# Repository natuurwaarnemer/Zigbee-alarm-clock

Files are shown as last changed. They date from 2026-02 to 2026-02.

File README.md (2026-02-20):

# Zigbee Wekker voor Home Assistant

Een slimme wekker gemaakt met ESP32-C6 die integreert met Home Assistant via WiFi (met Zigbee upgrade pad).

## Features

- 🕐 7 instelbare alarmen (één per dag van de week)
- 📱 Besturing via Home Assistant dashboard
- 🔊 Piëzo buzzer voor alarm met geleidelijk toenemend volume
- 🔘 Fysieke knop om alarm uit te zetten
- 💡 Triggert automatisch acties in Home Assistant (bijv. licht aan)
- 📟 OLED display (1.3", 128x64) toont tijd, datum en volgend alarm
- 📶 WiFi verbinding via ESPHome (Zigbee upgrade mogelijk)
- 🌙 Weergavehelderheid aanpasbaar (dim 's nachts)
- 🗓️ Weekend/werkdag modus

## Benodigdheden

| Component | Type | Opmerkingen |
|---|---|---|
| Microcontroller | ESP32-C6 (Seeed Studio) | Met ingebouwde WiFi + Zigbee |
| Display | OLED 1.3" 128x64 I2C | SSD1306 driver, blauw |
| Buzzer | Piezo buzzer (Grove/Actief) | 3-5V |
| Knop | Drukknop 19mm (DE-GQ19H-10) | Normaal open |
| Voeding | USB-C 5V adapter | Minimaal 1A |

Zie [hardware/components.md](hardware/components.md) voor de volledige lijst met bestelnummers.

## Snelstart

1. Sluit hardware aan volgens [hardware/wiring-diagram.md](hardware/wiring-diagram.md)
2. Volg [docs/SETUP.md](docs/SETUP.md) voor installatie en configuratie
3. Voeg Home Assistant helpers toe via [home-assistant/configuration.yaml](home-assistant/configuration.yaml)
4. Importeer het dashboard via [home-assistant/dashboard.yaml](home-assistant/dashboard.yaml)
5. (Optioneel) Print de behuizing via [3d-models/](3d-models/)

## Repository Structuur

```
Zigbee-alarm-clock/
├── esphome/
│   ├── zigbee-alarm-clock.yaml     # Primaire ESPHome configuratie (WiFi)
│   └── secrets.yaml.example        # Sjabloon voor WiFi/API gegevens
├── platformio/                     # Alternatief: native Zigbee (gevorderd)
│   ├── platformio.ini
│   ├── src/
│   │   ├── main.cpp
│   │   ├── display.cpp/h
│   │   ├── zigbee.cpp/h
│   │   └── alarm.cpp/h
│   └── README.md
├── home-assistant/
│   ├── configuration.yaml          # Helpers definitie
│   ├── automations.yaml            # Voorbeeldautomatiseringen
│   ├── dashboard.yaml              # Dashboard kaart
│   └── README.md
├── hardware/
│   ├── wiring-diagram.md           # Gedetailleerde aansluitgids
│   ├── components.md               # Onderdelen lijst (BOM)
│   └── photos/
├── 3d-models/
│   ├── case-v1.scad                # OpenSCAD bronbestand
│   └── README.md
├── docs/
│   ├── SETUP.md                    # Stap-voor-stap installatie
│   ├── TROUBLESHOOTING.md          # Veelvoorkomende problemen
│   └── ARCHITECTURE.md             # Systeemontwerp (Engels)
├── .gitignore
└── LICENSE
```

## Schermafdrukken / Foto's

> 📸 Foto's worden toegevoegd zodra de hardware is geassembleerd.
> Zie [hardware/photos/](hardware/photos/) voor placeholders.

## Technische Details

### Pinnen Configuratie

| Functie | GPIO |
|---|---|
| OLED SDA | GPIO6 |
| OLED SCL | GPIO7 |
| Buzzer (+) | GPIO8 |
| Knop | GPIO9 |

### Stroomverbruik

| Toestand | Stroom |
|---|---|
| Standby | ~80 mA |
| Display actief | ~100 mA |
| Alarm actief | ~120 mA |
| WiFi piek | ~150 mA |

## Zigbee Upgrade

Dit project gebruikt momenteel WiFi via ESPHome. De ESP32-C6 heeft ingebouwde
Zigbee hardware. Zodra ESPHome native Zigbee ondersteunt, is een upgrade mogelijk
zonder hardware wijzigingen. De `platformio/` map bevat een Zigbee implementatie
als referentie voor gevorderde gebruikers.

Zie [docs/ARCHITECTURE.md](docs/ARCHITECTURE.md) voor het migratiepad.

## Bekende Beperkingen

- ESPHome heeft nog geen native Zigbee ondersteuning voor ESP32-C6
- De buzzer vereist een actieve buzzer of passieve piëzo (zie BOM)
- OTA updates vereisen WiFi verbinding
- NTP tijd synchronisatie vereist internetverbinding

## Bijdragen

Pull requests zijn welkom! Zie [docs/ARCHITECTURE.md](docs/ARCHITECTURE.md) voor
de systeemarchitectuur en bijdragenrichtlijnen.

## Changelog

### v1.0.0 (2026)
- Initiële release
- ESPHome WiFi implementatie
- 7 instelbare alarmen
- OLED display
- Home Assistant integratie
- PlatformIO Zigbee referentie implementatie
- 3D printbare behuizing

## Licentie

MIT License - zie [LICENSE](LICENSE) voor details.

Copyright (c) 2026 Ruud Hogenberg

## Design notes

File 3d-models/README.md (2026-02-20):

# 3D-geprinte Behuizing - Zigbee Wekker

## Overzicht

De behuizing is ontworpen in OpenSCAD (parametrisch, aanpasbaar) en is 
printbaar zonder supports.

## Benodigdheden

| Item | Specificatie |
|---|---|
| 3D Printer | FDM printer, minimaal 100x80 mm printoppervlak |
| Filament | PLA 1.75 mm, ~50 gram |
| Kleur | Naar keuze (zwart aanbevolen) |

## Printinstellingen

| Instelling | Waarde |
|---|---|
| Laagdikte | 0.2 mm |
| Vulling | 20% (gyroid of grid) |
| Omtreklijnen | 3 |
| Printtemperatuur PLA | 200-210°C |
| Bed temperatuur | 60°C |
| Supports | NIET nodig |
| Brim | Aanbevolen (3-5 mm) voor het deksel |

## Onderdelen

Het model bestaat uit 2 onderdelen die apart worden afgedrukt:

### 1. Body (Onderstuk) - `case_body()`
- Buitenafmetingen: 100 x 75 x 40 mm
- Bevat: montage palen voor ESP32-C6 en OLED, USB-C poort uitsparing,
  snap-fit clips, kabelgeleiding
- Printoriëntatie: **Platte onderkant naar beneden** (geen supports nodig)

### 2. Deksel (Bovenstuk) - `case_lid()`
- Buitenafmetingen: 100 x 75 x 6 mm  
- Bevat: display venster uitsparing (35x28 mm), knop gat (19.5 mm Ø),
  snap-fit groeven
- Printoriëntatie: **Platte binnenkant naar beneden** (geen supports nodig)

## STL Exporteren vanuit OpenSCAD

### Body exporteren:
1. Open `case-v1.scad` in OpenSCAD
2. Zoek de render regels onderaan het bestand
3. Verwijder `//` voor `case_body();` en voeg `//` toe voor andere render regels
4. Klik F6 (Render)
5. Klik File → Export → Export as STL

### Deksel exporteren:
1. Zelfde procedure, maar activeer `case_lid();`

## Parameters Aanpassen

Open `case-v1.scad` en pas de parameters bovenaan het bestand aan:

```openscad
// Buitenafmetingen - vergroot voor meer ruimte binnenin
case_width  = 100;   // breedte in mm
case_depth  = 75;    // diepte in mm
case_height = 40;    // hoogte in mm
wall_thickness = 2.5; // wanddikte in mm
```

**Let op toleranties:** Bij grote printers of andere filamenttypes kan het nodig
zijn `fit_tol` aan te passen (standaard 0.2 mm).

## Assemblage

### Benodigdheden voor assemblage
- 4x M2x4mm schroeven (voor ESP32-C6)
- 4x M2x4mm schroeven (voor OLED module, optioneel)
- Dubbelzijdig tape of hot glue (alternatief voor schroeven)
- Kleine platte schroevendraaier

### Stappen
1. Druk beide onderdelen af
2. Verwijder brim/rand voorzichtig
3. Test of de snap-fit past (body + deksel klikken samen)
4. Monteer ESP32-C6 module op de 4 montage palen (M2 schroeven)
5. Monteer OLED display (gericht naar het display venster in het deksel)
6. Verleg kabels netjes via de kabelgeleiding
7. Klik het deksel op de body
8. Test alle functies voor definitieve montage

## Maatvoering

```
Bovenaanzicht deksel:
┌────────────────────────────────────────────┐
│                                            │
│    ┌──────────────────────┐    ○           │
│    │   Display venster    │  (knop)        │
│    │    35 x 28 mm        │   19.5mm Ø     │
│    └──────────────────────┘                │
│                                            │
└────────────────────────────────────────────┘
          100 mm breed x 75 mm diep

Zijaanzicht:
┌────────────────────────────────────────────┐  ← Deksel (6mm)
│                                            │
│                                            │
│                                            │  ← Body (40mm)
│  [USB-C]                                   │
└────────────────────────────────────────────┘
```

## Problemen Oplossen

**Deksel past niet:**
- Vergroot `fit_tol` van 0.2 naar 0.3 of 0.4 mm en herprint
- Schuur de binnenkant van de snap-fit groeven lichtjes bij

**Display venster te klein:**
- Meet je OLED module nauwkeurig na
- Pas `display_w` en `display_h` aan in het SCAD bestand

**Knop gat te nauw:**
- Pas `button_dia` aan (verhoog met 0.2-0.5 mm)

**Montagepalen te smal/breed:**
- Pas `post_hole_dia` aan voor M2 schroeven (standaard 2.1 mm)

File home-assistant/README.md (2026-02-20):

# Home Assistant Configuratie - Zigbee Wekker

## Overzicht

Deze map bevat de Home Assistant configuratie voor de Zigbee Wekker:

- `configuration.yaml` - Helpers (input_datetime, input_boolean)
- `automations.yaml` - Automatiseringen voor alarm sync en acties
- `dashboard.yaml` - Lovelace dashboard kaart

## Installatie

### Stap 1: Helpers toevoegen

Voeg de inhoud van `configuration.yaml` toe aan je Home Assistant
`configuration.yaml` (of aan een apart bestand via `!include`).

Herstart Home Assistant na het toevoegen van de helpers.

**Via de UI (aanbevolen):**
1. Ga naar Instellingen → Apparaten & Services → Helpers
2. Klik "+ Maak Helper"
3. Maak alle `input_datetime` en `input_boolean` helpers aan zoals beschreven

### Stap 2: Apparaat toevoegen (ESPHome)

1. Zorg dat de wekker is geflasht en verbonden met WiFi
2. Home Assistant detecteert het apparaat automatisch via ESPHome integratie
3. Ga naar Instellingen → Apparaten & Services → ESPHome
4. Accepteer het nieuwe apparaat "Zigbee Wekker"

### Stap 3: Automatiseringen toevoegen

**Via de UI:**
1. Ga naar Instellingen → Automatiseringen
2. Importeer `automations.yaml` of maak handmatig aan

**Via YAML:**
Voeg inhoud van `automations.yaml` toe aan je `automations.yaml`

### Stap 4: Dashboard toevoegen

1. Ga naar je gewenste dashboard
2. Klik het bewerkingspictogram (potlood)
3. Klik "Kaart toevoegen" → "Handmatig"
4. Plak de inhoud van `dashboard.yaml`

## Entiteiten

Na installatie zijn deze entiteiten beschikbaar:

### Van de wekker (ESPHome)
| Entiteit | Type | Beschrijving |
|---|---|---|
| `binary_sensor.zigbee_wekker_wifi_verbonden` | Sensor | WiFi status |
| `sensor.zigbee_wekker_volgend_alarm` | Sensor | Volgende alarm tijd |
| `sensor.zigbee_wekker_wifi_signaalsterkte` | Sensor | WiFi signaal (dBm) |
| `switch.zigbee_wekker_alarm_hoofdschakelaar` | Schakelaar | Master aan/uit |
| `switch.zigbee_wekker_alarm_maandag_aan` | Schakelaar | Maandag alarm |
| ... | ... | Herhaal voor alle 7 dagen |
| `number.zigbee_wekker_alarm_maandag_uur` | Nummer | Alarm uur |
| `number.zigbee_wekker_alarm_maandag_minuut` | Nummer | Alarm minuut |
| ... | ... | Herhaal voor alle 7 dagen |

### HA Helpers (aangemaakt via configuration.yaml)
| Entiteit | Type | Beschrijving |
|---|---|---|
| `input_datetime.alarm_maandag` | Tijd invoer | Alternatief tijdsinvoer |
| `input_boolean.alarm_maandag_aan` | Schakelaar | Alternatief schakelaar |
| `input_boolean.alarm_hoofdschakelaar` | Schakelaar | Hoofd schakelaar HA kant |

## Troubleshooting

**Apparaat verschijnt niet:**
- Controleer WiFi verbinding
- Herstart de ESPHome integratie
- Check de logs: Instellingen → Systeem → Logboek

**Alarm synchroniseert niet:**
- Check dat de automatisering actief is
- Verifieer entiteitsnamen in de automatisering
- Bekijk trace in automatiseringseditor

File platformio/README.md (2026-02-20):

# PlatformIO - Native Zigbee Implementatie (Gevorderd)

Dit is de **alternatieve** implementatie van de Zigbee Wekker met native Zigbee
via de ESP-Zigbee-SDK. De primaire implementatie (via ESPHome + WiFi) staat in
de `esphome/` map.

## Wanneer deze versie gebruiken?

Gebruik de PlatformIO versie als je:
- Native Zigbee communicatie wilt (geen WiFi vereist)
- Meer controle wilt over de Zigbee device definitie
- Gevorderd bent met embedded programmeren
- Een Zigbee coordinator hebt (bijv. SMLIGHT SLZB-MR3 of Sonoff Zigbee Dongle)

## Vereisten

### Software
- [PlatformIO IDE](https://platformio.org/) (VS Code extensie aanbevolen)
- ESP-IDF v5.x (automatisch geïnstalleerd door PlatformIO)
- ESP-Zigbee-SDK (via ESP-IDF component manager)

### Hardware
- ESP32-C6 development board (Seeed Studio XIAO ESP32C6 of vergelijkbaar)
- Zigbee coordinator op hetzelfde netwerk als Home Assistant

## Installatie

### Stap 1: PlatformIO installeren

1. Installeer [VS Code](https://code.visualstudio.com/)
2. Installeer de PlatformIO extensie
3. Open de `platformio/` map als project

### Stap 2: ESP-Zigbee-SDK component toevoegen

Maak een `idf_component.yml` aan in de `platformio/` map:

```yaml
dependencies:
  espressif/esp-zigbee-sdk: ">=1.1.0"
```

Of voeg toe via ESP-IDF component manager:
```bash
cd platformio
idf.py add-dependency "espressif/esp-zigbee-sdk"
```

### Stap 3: sdkconfig aanpassen

Maak een `sdkconfig.defaults` bestand aan in de `platformio/` map:

```
CONFIG_ZB_ENABLED=y
CONFIG_ZB_ZED=y
CONFIG_ZB_RADIO_NATIVE=y
CONFIG_ZB_GP_ENABLED=n
CONFIG_FREERTOS_HZ=1000
```

### Stap 4: Compileren en uploaden

```bash
cd platformio
pio run --target upload
pio device monitor --baud 115200
```

## Zigbee Configuratie in Home Assistant

### MQTT/Zigbee2MQTT

Als je Zigbee2MQTT gebruikt, wordt het apparaat automatisch gedetecteerd als
een "Alarm Clock" device na pairen.

**Pairen:**
1. Zet het apparaat in pairmodus (eerste keer automatisch, daarna via serieel commando)
2. Open Zigbee2MQTT dashboard
3. Klik "Permit join"
4. Het apparaat verschijnt als "Zigbee Alarm Clock"

### ZHA (Zigbee Home Automation)

1. Ga naar Instellingen → Apparaten & Services → ZHA
2. Klik "Apparaat toevoegen"
3. Druk de resetknop op het ESP32-C6 board

## Codestructuur

```
platformio/src/
├── main.cpp      # Arduino setup/loop, button handling, time management
├── display.cpp   # SSD1306 OLED rendering
├── display.h     # Display API
├── alarm.cpp     # Alarm logic, NVS storage, buzzer PWM
├── alarm.h       # Alarm API
├── zigbee.cpp    # Zigbee stack, clusters, attribute handling
└── zigbee.h      # Zigbee API
```

## Bekende Beperkingen

- ESP-Zigbee-SDK is nog in actieve ontwikkeling - API kan veranderen
- Arduino framework heeft beperkte compatibiliteit met ESP-Zigbee-SDK
  (gebruik `espidf` framework voor productie)
- Geen OTA via Zigbee (gebruik seriële verbinding voor updates)
- Zigbee2MQTT heeft mogelijk custom converter nodig voor het custom cluster

## Referenties

- [ESP-Zigbee-SDK GitHub](https://github.com/espressif/esp-zigbee-sdk)
- [ESP-IDF Zigbee Examples](https://github.com/espressif/esp-idf/tree/master/examples/zigbee)
- [Zigbee2MQTT Custom Devices](https://www.zigbee2mqtt.io/advanced/support-new-devices/01_support_new_devices.html)

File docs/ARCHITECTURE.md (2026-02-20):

# System Architecture - Zigbee Alarm Clock

## Overview

The Zigbee Alarm Clock is a WiFi/Zigbee-enabled smart alarm clock built on the
ESP32-C6 microcontroller. It integrates with Home Assistant for alarm management
and automation.

```
┌─────────────────────────────────────────────────────────────────┐
│                      Home Assistant                             │
│  ┌─────────────────────────────────────────────────────────┐   │
│  │  ESPHome Integration   │  Input Helpers  │  Dashboard   │   │
│  └─────────────────────────────────────────────────────────┘   │
└──────────────────────────────┬──────────────────────────────────┘
                               │ WiFi (ESPHome native API)
                               │ or Zigbee (future / platformio/)
┌──────────────────────────────▼──────────────────────────────────┐
│                       ESP32-C6                                  │
│                                                                 │
│  ┌──────────────┐  ┌──────────────┐  ┌──────────────────────┐  │
│  │  ESPHome     │  │  Alarm Logic │  │   Display Driver     │  │
│  │  Framework   │  │  (Globals +  │  │   (SSD1306 I2C)      │  │
│  │  (WiFi/API)  │  │   Scripts)   │  │   GPIO6/7            │  │
│  └──────────────┘  └──────────────┘  └──────────────────────┘  │
│         │                │                                      │
│  ┌──────▼──────┐  ┌──────▼──────┐  ┌──────────────────────┐   │
│  │  NTP / HA   │  │  PWM Buzzer │  │   Button Handler     │   │
│  │  Time Sync  │  │  (LEDC)     │  │   GPIO9 (pull-up)    │   │
│  └─────────────┘  │  GPIO8      │  └──────────────────────┘   │
│                   └─────────────┘                               │
└─────────────────────────────────────────────────────────────────┘
        │                    │                    │
   ┌────▼────┐          ┌────▼────┐          ┌────▼────┐
   │  OLED   │          │  Buzzer │          │  Button │
   │ 128x64  │          │ GPIO8   │          │ GPIO9   │
   └─────────┘          └─────────┘          └─────────┘
```

## Components

### 1. ESPHome Firmware (`esphome/`)

**Primary implementation** - recommended for most users.

| Component | Implementation |
|---|---|
| Time sync | `homeassistant` platform + SNTP fallback |
| Display | `ssd1306_i2c` platform, lambda rendering |
| Alarm logic | `script` components + `globals` |
| Button | `gpio` binary_sensor with debounce |
| Buzzer | `ledc` PWM output + manual control in scripts |
| WiFi | Native ESP32 WiFi + captive portal fallback |
| HA API | Native ESPHome API (encrypted) |

**Alarm checking:** A `script` runs every minute triggered by `on_time`.
It checks each day's alarm against current time and day-of-week. If a match
is found, the `alarm_start` script is invoked.

**Display rendering:** The display lambda runs every second. It reads globals
(`alarm_active`, `next_alarm_str`) and the HA time component to render the UI.
During an active alarm, the display blinks to attract attention.

**Fade-in buzzer:** The `alarm_beep_loop` script uses a global `buzzer_step`
(0-10) to gradually increase the PWM duty cycle over the first 10 beep cycles,
creating a gentle wake-up experience.

### 2. Home Assistant

**Alarm configuration storage:**
- `number` entities (hour/minute per day) - stored on the ESP32 in flash
- `switch` entities (enabled per day) - stored on the ESP32 in flash
- `input_datetime` / `input_boolean` helpers - optional HA-side storage

**Automations:**
- Sync helpers → device number/switch entities
- Trigger lights/scenes on button press event
- Send mobile notification on alarm trigger
- Vacation mode (disable all alarms)

**Dashboard:** Lovelace vertical-stack card with entities, buttons for test/stop.

### 3. PlatformIO / Native Zigbee (`platformio/`)

**Alternative implementation** for advanced users wanting native Zigbee.

| Module | File | Responsibility |
|---|---|---|
| Main loop | `main.cpp` | Setup, loop, button, time integration |
| Display | `display.cpp/h` | SSD1306 Adafruit driver, all rendering |
| Alarm | `alarm.cpp/h` | Alarm logic, buzzer PWM, NVS storage |
| Zigbee | `zigbee.cpp/h` | ESP-Zigbee-SDK, clusters, HA communication |

**Zigbee device profile:** End Device (ZED) on HA profile.
Custom cluster `0xFF00` for alarm configuration attributes.
On/Off cluster for button events and master switch.

## Data Flow

### WiFi Version (ESPHome) - Normal Operation

```
HA Dashboard          ESPHome Device (ESP32-C6)         Hardware
────────────          ──────────────────────────         ────────
User sets alarm  ───► number.set_value (hour/min)
User enables day ───► switch.turn_on (day_en)
                       │
                       ▼ (every minute, on_time trigger)
                      check_alarms()
                       │ match found
                       ▼
                      alarm_start()  ──────────────────► Buzzer ON
                      alarm_active=true ──────────────► Display blinks
                       │
                       │ ◄────────────────────────────── Button pressed
                      alarm_stop()
                      alarm_active=false
                       │
                       ▼
                      homeassistant.event(button_pressed) ─► HA Automation
                                                              └─► Light ON
```

### Time Synchronization

```
internet/NTP                Home Assistant              ESP32-C6
────────────                ──────────────              ────────
NTP servers ─────────────► HA system time ────────────► homeassistant_time
                                                          (syncs on connect)
                                                          + SNTP fallback
```

## Storage

### On-Device (ESP32-C6 Flash)
- 7x alarm hour (0-23) - ESPHome: `restore_value: true` on number entities
- 7x alarm minute (0-59) - ESPHome: `restore_value: true`
- 7x alarm enabled - ESPHome: switch with `RESTORE_DEFAULT_OFF`
- Master switch state - ESPHome: switch with `RESTORE_DEFAULT_ON`

ESPHome uses the NVS (Non-Volatile Storage) partition automatically for
entities with `restore_value: true` or switches with `RESTORE_DEFAULT_*`.

### In Home Assistant
- `input_datetime` helpers (optional, for HA-side scheduling)
- `input_boolean` helpers (optional)
- Automation state

## Security

- ESPHome API uses AES-256-CBC encryption (`api_encryption_key`)
- OTA updates protected by password (`ota_password`)
- WiFi credentials stored in `secrets.yaml` (not committed to git)
- No external services used (all local)

## Future: Zigbee Migration Path

The ESP32-C6 has built-in Zigbee hardware (IEEE 802.15.4).
Currently ESPHome does not support native Zigbee for ESP32-C6.

**Migration steps when ESPHome Zigbee support matures:**
1. Replace `wifi:` block with `zigbee:` configuration
2. Replace `api:` (ESPHome API) with Zigbee cluster definitions
3. Update HA integration from ESPHome to ZHA/Zigbee2MQTT
4. No hardware changes required

**Current Zigbee implementation** (PlatformIO):
- Uses ESP-Zigbee-SDK directly (ESP-IDF component)
- Custom Zigbee cluster 0xFF00 for alarm configuration
- On/Off cluster for button events
- See `platformio/` for full implementation

## Known Limitations

1. **ESPHome Zigbee:** Not yet supported for ESP32-C6 in stable ESPHome
2. **OTA requires WiFi:** No air-gap updates possible in WiFi mode
3. **Single endpoint:** One alarm clock instance per ESPHome device
4. **Time zone:** Hardcoded to `Europe/Amsterdam` - change in yaml if needed
5. **Font rendering:** Requires internet connection at compile time for Google Fonts

## Performance

| Metric | Value | Notes |
|---|---|---|
| Boot time | ~3s | ESP-IDF framework |
| Display update | 1s | ESPHome timer |
| Alarm check latency | ≤60s | Checked every minute at :00 |
| Button response | <100ms | GPIO interrupt + 20ms debounce |
| WiFi reconnect | ~5s | Auto reconnect |
| Memory usage | ~180KB | ESP-IDF heap |

## Contributing

1. Fork the repository
2. Create a feature branch
3. Follow existing code style (English comments, Dutch UI text)
4. Test on real hardware when possible
5. Submit a pull request with description of changes

### Code Style
- ESPHome YAML: comments in English, all user-facing text in Dutch
- C++ (PlatformIO): Google C++ style, 4-space indent, English comments
- Markdown docs: Dutch for user documentation, English for ARCHITECTURE.md

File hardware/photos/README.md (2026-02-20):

# Foto's en Afbeeldingen

> 📸 Foto's worden toegevoegd zodra de hardware is geassembleerd.

## Geplande foto's

- [ ] Overzichtsfoto compleet apparaat
- [ ] Display close-up met tijdweergave
- [ ] Binnenaanzicht met bedrading
- [ ] Aansluitschema foto
- [ ] 3D-geprinte behuizing
- [ ] Home Assistant dashboard screenshot

## Bijdragen

Heb je het project gebouwd? Stuur je foto's via een Pull Request!
Gebruik de naam `foto-NNN-beschrijving.jpg` (bijv. `foto-001-overzicht.jpg`).

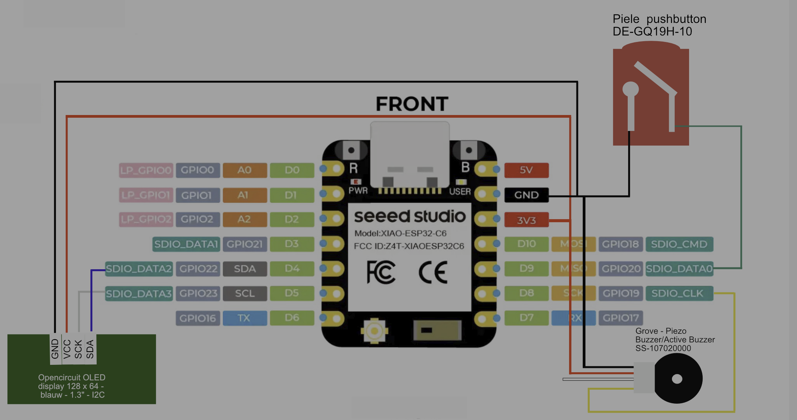
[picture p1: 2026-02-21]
docs/Wekkerradio_ED.png

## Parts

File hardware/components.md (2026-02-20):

# Materiaallijst (BOM) - Zigbee Wekker

## Benodigde Onderdelen

| # | Component | Specificatie | Hoeveelheid | Prijs (ca.) | Bestelcode (voorbeeld) |
|---|---|---|---|---|---|
| 1 | Microcontroller | Seeed Studio XIAO ESP32-C6 | 1 | €8,00 | Seeed 113991054 |
| 2 | OLED Display | 1.3" 128x64 I2C SSD1306 (blauw) | 1 | €7,00 | AliExpress/Amazon |
| 3 | Buzzer | Actieve piezo buzzer 3.3V-5V | 1 | €1,50 | Grove 107020000 |
| 4 | Drukknop | 19mm momenteel normaal-open | 1 | €3,00 | DE-GQ19H-10 |
| 5 | USB-C kabel | USB-C naar USB-A of USB-C naar USB-C | 1 | €4,00 | - |
| 6 | USB-C adapter | 5V / 1A minimum | 1 | €8,00 | Diverse merken |
| 7 | Prototype PCB | 7x9 cm soldeereiland PCB (optioneel) | 1 | €2,00 | - |
| 8 | Jumperwires | Dupont male-female jumpers | ~10 | €3,00 | Set van 40 |
| 9 | Pin headers | 2.54 mm male headers | 2 rijen | €1,00 | - |
| 10 | 3D print filament | PLA 1.75mm (zwart) | ~50 gram | €1,50 | Diverse merken |

**Totaal (geschat): €39,00**

## Alternatieve Componenten

### Microcontroller Alternatieven
| Variant | Opmerking |
|---|---|
| ESP32-C6 DevKit (Espressif) | Groter formaat, meer GPIO's beschikbaar |
| ESP32-C6 (andere fabrikant) | Let op pinout verschil! |

### Display Alternatieven
| Variant | Opmerking |
|---|---|
| SSD1306 0.96" 128x64 | Kleiner display, zelfde driver |
| SH1106 1.3" 128x64 | Andere driver - aanpassen in ESPHome: `model: "SH1106 128x64"` |
| SSD1306 wit (i.p.v. blauw) | Zelfde aansluitingen |

### Buzzer Alternatieven
| Variant | Opmerking |
|---|---|
| Passieve piezo buzzer | Ondersteund via LEDC PWM - behoudt melodie mogelijkheid |
| Grove buzzer module | Heeft eigen transistor driver |
| KY-012 buzzer module | Directe GPIO aansluiting |

### Knop Alternatieven
| Variant | Opmerking |
|---|---|
| 12mm drukknop | Kleiner, past in compactere behuizing |
| Arcade knop 30mm | Groter, makkelijker te bedienen half-wakker |
| Captatieve touchknop | Geen mechanische slijtage |

## Gereedschap

| Item | Gebruik |
|---|---|
| Soldeerbout + soldeertin | Solderen van pinnen/wires |
| Kniptang | Draadjes knippen |
| Striptang | Isolatie verwijderen |
| Multimeter | Verbindingen testen |
| USB naar serieel adapter | Eerste keer flashen (of via USB direct) |
| 3D printer | Behuizing afdrukken |

## Waar Bestellen?

### Nederland/België
- **Kiwi Electronics** (kiwi-electronics.com) - ESP32-C6, displays, Arduino componenten
- **AliExpress** - Voordelig, langere levertijd (2-4 weken)
- **Amazon.nl** - Snelle levering, iets duurder
- **Mouser** / **DigiKey** - Professionele componenten, vaak duurder

### Directe Links (controleer actualiteit)
- XIAO ESP32-C6: https://www.seeedstudio.com/Seeed-Studio-XIAO-ESP32C6-p-5884.html
- Grove Buzzer: https://www.seeedstudio.com/Grove-Buzzer.html

## Opmerkingen bij de Onderdelen

**ESP32-C6:** De XIAO variant van Seeed Studio is compact (21x17.5mm) en heeft
een ingebouwde RGB LED. Ideaal voor kleine behuizingen. Let op: de pinout wijkt
af van standaard ESP32 dev boards.

**OLED Display:** Koop een module met 4-pins I2C aansluiting (VCC, GND, SCL, SDA).
Sommige modules hebben een RST-pin - die laat je onverbonden of verbindt met een
GPIO (niet nodig voor SSD1306).

**Buzzer:** Een **actieve** buzzer heeft een ingebouwde oscillator en maakt geluid
bij vaste spanning. Een **passieve** buzzer heeft PWM nodig maar kan melodieën
spelen. Beide worden ondersteund door de ESPHome configuratie.

**Drukknop:** De DE-GQ19H-10 is een robuuste 19mm panelknop. Zorg dat je de
normaal-open (NO) variant hebt, niet normaal-gesloten (NC).

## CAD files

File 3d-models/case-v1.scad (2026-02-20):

// case-v1.scad - Zigbee Wekker Behuizing v1
// Parametrisch ontwerp voor ESP32-C6 + SSD1306 OLED + Buzzer + Knop
//
// Afdrukken zonder supports:
//   - Body en deksel apart afdrukken
//   - Body: flat onderkant naar beneden
//   - Deksel: flat binnenkant naar beneden
//
// Toleranties: 0.2 mm voor snap-fit verbindingen
// Aanbevolen instellingen: 0.2mm laagdikte, 20% vulling, 2 omtreklijnen

// ============================================================
// Parameters - Pas hier aan naar wens
// ============================================================

// Buitenafmetingen behuizing
case_width      = 100;   // mm breedte (X)
case_depth      = 75;    // mm diepte (Y)
case_height     = 40;    // mm hoogte totaal (zonder deksel)
wall_thickness  = 2.5;   // mm wanddikte

// Display venster (SSD1306 1.3" 128x64)
display_w       = 35;    // mm breedte zichtbaar gedeelte
display_h       = 28;    // mm hoogte zichtbaar gedeelte
display_offset_x = 0;    // mm horizontale offset van midden (0 = gecentreerd)
display_offset_y = 5;    // mm van bovenrand deksel

// USB-C poort gat (zijkant)
usbc_w          = 10;    // mm breedte
usbc_h          = 4;     // mm hoogte
usbc_offset_y   = 8;     // mm van onderkant

// Knop gat (bovenkant deksel, rechts)
button_dia      = 19.5;  // mm diameter (19mm knop + 0.5mm speling)
button_offset_x = 30;    // mm van midden naar rechts
button_offset_y = 0;     // mm van midden (0 = gecentreerd Y)

// Buzzer gaten (onderkant of zijkant)
buzzer_hole_dia    = 3;   // mm diameter per gat
buzzer_hole_rows   = 3;   // aantal rijen
buzzer_hole_cols   = 4;   // aantal kolommen
buzzer_hole_pitch  = 5;   // mm tussenruimte gaten

// Montage pinnen (voor ESP32-C6 module)
post_dia        = 4;     // mm buitendiameter
post_hole_dia   = 2.1;   // mm gat voor M2 schroef
post_height     = 5;     // mm hoogte paal
// ESP32-C6 XIAO montagegaten (21x17.5 mm, gaatjes op hoeken)
mount_spacing_x = 16.5;
mount_spacing_y = 13.0;
mount_offset_x  = -10;   // positie van ESP32 module in behuizing
mount_offset_y  = 5;

// Snap-fit clips
snap_count      = 3;     // aantal clips per lange zijkant
snap_width      = 8;     // mm breedte per clip
snap_depth      = 1.5;   // mm insprong snap
snap_height     = 3;     // mm hoogte clip

// Kabelgeleiding
cable_channel_w = 6;
cable_channel_h = 3;

// Tolerantie voor passen
fit_tol         = 0.2;

// ============================================================
// Afgeleid
// ============================================================

inner_w = case_width  - 2 * wall_thickness;
inner_d = case_depth  - 2 * wall_thickness;

// ============================================================
// Modules
// ============================================================

// Afgeronde rechthoek (2D)
module rounded_rect(w, d, r) {
    offset(r) offset(-r) square([w, d], center=true);
}

// Afgeronde doos (3D)
module rounded_box(w, d, h, r=2) {
    linear_extrude(h) rounded_rect(w, d, r);
}

// Holle doos (wanden + bodem)
module hollow_box(w, d, h, wall, r=2) {
    difference() {
        rounded_box(w, d, h, r);
        translate([0, 0, wall])
            rounded_box(w - 2*wall, d - 2*wall, h, r - wall);
    }
}

// Montagepaal met M2 gat
module mount_post(h) {
    difference() {
        cylinder(d=post_dia, h=h, $fn=16);
        cylinder(d=post_hole_dia, h=h+1, $fn=16);
    }
}

// Snap-fit clip (voor aan de binnenkant van de zijwand)
module snap_clip() {
    hull() {
        cube([snap_width, snap_depth, snap_height], center=true);
        translate([0, snap_depth/2, snap_height/2])
            cube([snap_width, 0.1, 0.1], center=true);
    }
}

// Buzzer gaten patroon
module buzzer_holes(rows, cols, dia, pitch) {
    for (r = [0:rows-1]) {
        for (c = [0:cols-1]) {
            translate([
                (c - (cols-1)/2) * pitch,
                (r - (rows-1)/2) * pitch,
                0
            ])
            cylinder(d=dia, h=wall_thickness*3, center=true, $fn=12);
        }
    }
}

// ============================================================
// Onderdeel 1: Behuizing Body (onderstuk)
// ============================================================
module case_body() {
    difference() {
        // Buitenwanden + bodem
        hollow_box(case_width, case_depth, case_height, wall_thickness);

        // USB-C poort gat (linkerzijkant)
        translate([
            -case_width/2 - 1,
            0,
            wall_thickness + usbc_offset_y + usbc_h/2
        ])
        cube([wall_thickness + 2, usbc_w, usbc_h], center=true);

        // Kabelgeleiding aan onderkant (optioneel)
        translate([0, case_depth/2 - wall_thickness/2, wall_thickness/2])
        cube([cable_channel_w, wall_thickness*2, cable_channel_h], center=true);
    }

    // Snap-fit clips aan de binnenzijde (voor deksel)
    clip_z = case_height - snap_height/2 - 1;

    // Lange zijden (voor/achter)
    for (side = [-1, 1]) {
        for (i = [0:snap_count-1]) {
            x_pos = (i - (snap_count-1)/2) * (inner_w / snap_count);
            translate([x_pos, side * (case_depth/2 - wall_thickness - snap_depth/2), clip_z])
            rotate([0, 0, side == 1 ? 0 : 180])
            snap_clip();
        }
    }

    // Montagepalen voor ESP32-C6
    for (dx = [-1, 1]) {
        for (dy = [-1, 1]) {
            translate([
                mount_offset_x + dx * mount_spacing_x/2,
                mount_offset_y + dy * mount_spacing_y/2,
                wall_thickness
            ])
            mount_post(post_height);
        }
    }

    // Montagepalen voor OLED display (posities afhankelijk van module)
    // OLED module typisch 38x38 mm met gaten op 32x32 mm
    for (dx = [-1, 1]) {
        for (dy = [-1, 1]) {
            translate([
                display_offset_x + dx * 16,
                -case_depth/2 + wall_thickness + 20 + dy * 16,
                wall_thickness
            ])
            mount_post(post_height);
        }
    }
}

// ============================================================
// Onderdeel 2: Deksel (bovenstuk)
// ============================================================
module case_lid() {
    lid_h = wall_thickness + 3; // dikke deksel voor stevigheid

    difference() {
        union() {
            // Dekselplaat
            rounded_box(case_width, case_depth, lid_h);

            // Rand die in de body past (met fit tolerantie)
            translate([0, 0, -3])
            difference() {
                rounded_box(
                    case_width - 2*(wall_thickness + fit_tol),
                    case_depth - 2*(wall_thickness + fit_tol),
                    4
                );
                rounded_box(
                    case_width - 4*wall_thickness - 2*fit_tol - snap_depth*2,
                    case_depth - 4*wall_thickness - 2*fit_tol - snap_depth*2,
                    4.5
                );
            }
        }

        // Display venster uitsparing
        translate([display_offset_x, case_depth/2 - display_offset_y - display_h/2, -1])
        cube([display_w, display_h, lid_h+2], center=true);

        // Knop gat
        translate([button_offset_x, button_offset_y, -1])
        cylinder(d=button_dia, h=lid_h+2, $fn=32);

        // Snap-fit groeven (voor de clips van de body)
        for (side = [-1, 1]) {
            for (i = [0:snap_count-1]) {
                x_pos = (i - (snap_count-1)/2) * (inner_w / snap_count);
                translate([
                    x_pos,
                    side * (case_depth/2 - wall_thickness - snap_depth),
                    -3 - snap_height/2
                ])
                cube([snap_width + fit_tol, snap_depth + fit_tol, snap_height + 1], center=true);
            }
        }
    }
}

// ============================================================
// Renderen
// Gebruik $fn=32 of hoger voor smoother export
// ============================================================

$fn = 32;

// Toon body
case_body();

// Toon deksel naast de body (voor preview)
translate([0, 0, case_height + 5])
    case_lid();

// Om alleen de body te exporteren als STL:
// case_body();

// Om alleen de deksel te exporteren als STL:
// case_lid();

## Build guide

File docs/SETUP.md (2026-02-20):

# Installatie Handleiding - Zigbee Wekker

> **Niveau:** Beginner (geen eerdere ESPHome ervaring vereist)
> **Tijdsduur:** 2-3 uur eerste keer, 30-60 minuten voor ervaren gebruikers

## Overzicht

Na deze handleiding heb je:
- ✅ Hardware aangesloten
- ✅ ESPHome firmware geflasht op de ESP32-C6
- ✅ Wekker verbonden met Home Assistant
- ✅ Alarm tijden instelbaar via dashboard

---

## Stap 1: Hardware Aansluiten

> 📸 [Foto placeholder: overzicht bedrading]

Sluit alle componenten aan **voor** je de voeding aansluit.

### 1.1 Wat je nodig hebt
- ESP32-C6 module (Seeed Studio XIAO ESP32-C6)
- OLED display 1.3" SSD1306
- Actieve buzzer
- Drukknop 19mm
- Jumperwires (Dupont female-female)
- USB-C kabel voor flashen

### 1.2 Verbindingen maken

Volg de tabel exact op. **Let op de 3.3V voor het OLED display - gebruik nooit 5V!**

### ⚠️ LET OP: Pin nummering XIAO ESP32-C6

De XIAO ESP32-C6 heeft **D-nummers** op de pinnen staan (D0, D1, D2, etc.), maar deze komen **NIET** overeen met GPIO nummers!

**Controleer altijd de pinout diagram:**
- Sluit de OLED SDA aan op **D4** (dit is GPIO22)
- Sluit de OLED SCL aan op **D5** (dit is GPIO23)
- Sluit de Buzzer aan op **D8** (dit is GPIO19)
- Sluit de Button aan op **D9** (dit is GPIO20)

De ESPHome configuratie gebruikt de correcte GPIO nummers automatisch.

| OLED Pin | ESP32-C6 Pin |
|---|---|
| VCC | 3.3V |
| GND | GND |
| SDA | D4 (GPIO22) |
| SCL | D5 (GPIO23) |

| Buzzer Pin | ESP32-C6 Pin |
|---|---|
| + (lang) | D8 (GPIO19) |
| - (kort) | GND |

| Knop Pin | ESP32-C6 Pin |
|---|---|
| Pin 1 | D9 (GPIO20) |
| Pin 2 | GND |

> 📸 [Foto placeholder: aansluitingen close-up]

### 1.3 Verbindingen controleren

Controleer voor je de voeding aansluit:
- [ ] OLED VCC verbonden met 3.3V (niet 5V!)
- [ ] Alle GND draden verbonden
- [ ] SDA op D4 (GPIO22), SCL op D5 (GPIO23)
- [ ] Buzzer + op D8 (GPIO19)
- [ ] Knop op D9 (GPIO20) en GND

---

## Stap 2: ESPHome Installeren in Home Assistant

> 📸 [Screenshot placeholder: HA instellingen menu]

### 2.1 ESPHome add-on installeren

1. Open **Home Assistant** in je browser
2. Ga naar **Instellingen** (linker menu, tandwiel icoon)
3. Klik **Add-ons**
4. Klik de blauwe knop **Add-on Store** (rechtsonder)
5. Zoek naar **ESPHome**
6. Klik op **ESPHome Device Compiler**
7. Klik **Installeren** en wacht (~2 minuten)
8. Schakel in: **Start bij opstarten** en **Tonen in zijbalk**
9. Klik **Starten**

> 📸 [Screenshot placeholder: ESPHome add-on pagina]

---

## Stap 3: Configuratie Bestand Aanmaken

### 3.1 secrets.yaml aanmaken

Maak een kopie van `esphome/secrets.yaml.example` en hernoem naar `secrets.yaml`:

```yaml
wifi_ssid: "NaamVanJeWifi"        # jouw WiFi naam
wifi_password: "WifiWachtwoord"   # jouw WiFi wachtwoord
api_encryption_key: ""            # zie stap 3.2
ota_password: "kies_een_wachtwoord"
```

### 3.2 API sleutel genereren

1. Ga naar de ESPHome add-on (via zijbalk)
2. Klik **Nieuw apparaat** of gebruik de dashboard
3. Of genereer handmatig via de terminal:
   ```bash
   openssl rand -base64 32
   ```
4. Plak de gegenereerde sleutel als `api_encryption_key` in secrets.yaml

### 3.3 Configuratie uploaden

De bestanden staan al klaar in de `esphome/` map van dit project.
Kopieer ze naar de ESPHome configuratiemap:

**Via Samba add-on (aanbevolen):**
1. Installeer de **Samba share** add-on in HA
2. Verbind met `\\homeassistant\config\esphome\`
3. Kopieer `zigbee-alarm-clock.yaml` en `secrets.yaml` naar die map

**Via de ESPHome add-on editor:**
1. Open ESPHome in de zijbalk
2. Klik **Nieuw Apparaat** → **Nee, ga handmatig verder**
3. Voer in als naam: `zigbee-alarm-clock`
4. Klik **ESP32-C6**
5. Vervang de gehele configuratie met de inhoud van `esphome/zigbee-alarm-clock.yaml`

---

## Stap 4: ESP32-C6 Flashen

### 4.1 ESP32-C6 verbinden met computer

1. Verbind de ESP32-C6 met een **USB-C kabel** met je computer
   (zorg dat het een datakabel is, niet alleen een oplaadkabel!)
2. De computer herkent het als een USB serieel apparaat

### 4.2 Eerste keer flashen (via browser - makkelijkst)

1. Ga naar de ESPHome add-on in Home Assistant
2. Je ziet het apparaat `zigbee-alarm-clock` in de lijst
3. Klik **Installeren** (of de 3 puntjes → Installeren)
4. Kies **Verbinden via USB**
5. Selecteer de COM-poort / tty-poort van de ESP32-C6

> 📸 [Screenshot placeholder: ESPHome apparaat installeren]

**Als de COM-poort niet zichtbaar is:**
- Windows: installeer [CP210x driver](https://www.silabs.com/developers/usb-to-uart-bridge-vcp-drivers)
- Mac/Linux: poort verschijnt als `/dev/ttyUSB0` of `/dev/ttyACM0`

### 4.3 Flashen via ESPHome web interface

Alternatief zonder HA add-on:
1. Ga naar [web.esphome.io](https://web.esphome.io) in Chrome
2. Klik **Connect**
3. Selecteer de poort
4. Klik **Install** → upload de gecompileerde firmware

### 4.4 Wachten op voltooiing

Het flashen duurt 2-5 minuten. Je ziet:
```
INFO Compiling project...
INFO Linking...
INFO Flashing...
INFO Done!
```

Na het flashen herstart de ESP32-C6 automatisch.

---

## Stap 5: Verbinding met Home Assistant

### 5.1 Apparaat toevoegen

Na het flashen en opstarten:
1. HA toont een melding: **Nieuw apparaat ontdekt: Zigbee Wekker**
2. Klik de melding
3. Klik **Configureren**
4. Voer de API sleutel in (dezelfde als in secrets.yaml)
5. Klik **Indienen**

> 📸 [Screenshot placeholder: HA apparaat toevoegen melding]

**Geen melding?**
- Ga naar Instellingen → Apparaten & Services → **Integraties toevoegen**
- Zoek **ESPHome** en klik erop
- Voer het IP-adres in van de wekker (zie je router DHCP tabel)

### 5.2 Verbinding verifiëren

1. Ga naar Instellingen → Apparaten & Services → ESPHome
2. Je ziet **Zigbee Wekker** als verbonden apparaat
3. Klik erop voor alle entiteiten

---

## Stap 6: Home Assistant Configureren

### 6.1 Helpers aanmaken

Voeg de helpers toe aan Home Assistant (voor het dashboard):

**Via de UI (aanbevolen):**
1. Instellingen → Apparaten & Services → **Helpers** tab
2. Klik **+ Maak Helper**
3. Kies **Datum/tijd** → naam: "Alarm Maandag", type: Tijd
4. Herhaal voor alle 7 dagen (Di, Wo, Do, Vr, Za, Zo)
5. Maak ook **Schakelaar** helpers aan voor "Alarm Maandag Aan" etc.

**Via YAML (gevorderd):**
Voeg de inhoud van `home-assistant/configuration.yaml` toe aan je HA configuration.yaml

### 6.2 Automatiseringen toevoegen

1. Instellingen → Automatiseringen
2. Klik **Importeren** (of maak handmatig aan)
3. Kopieer inhoud van `home-assistant/automations.yaml`
4. **Pas aan:** verander `light.slaapkamer` naar jouw lamp entiteit

### 6.3 Dashboard toevoegen

1. Ga naar je gewenste dashboard
2. Klik het **potlood icoon** (bewerken)
3. Klik **+ Kaart toevoegen** → **Handmatig**
4. Plak inhoud van `home-assistant/dashboard.yaml`
5. Klik **Opslaan**

> 📸 [Screenshot placeholder: dashboard voorbeeld]

---

## Stap 7: Testen

### 7.1 Basisfuncties controleren

- [ ] **Display:** Toont de huidige tijd (gesynchroniseerd met HA)
- [ ] **WiFi icoon:** "W" zichtbaar in de rechterbovenhoek van het display
- [ ] **Alarm icoon:** "ON" zichtbaar als hoofdschakelaar aan staat

### 7.2 Alarm instellen en testen

1. Ga naar het wekker dashboard in Home Assistant
2. Stel een alarm in op 2 minuten in de toekomst
3. Schakel de dag schakelaar aan
4. Wacht tot het alarm afgaat

**Alarm test via HA:**
1. Ga naar Ontwikkeltools → Services
2. Zoek `esphome.zigbee_wekker_trigger_alarm`
3. Klik **Service aanroepen** - het alarm gaat direct af!

### 7.3 Knop testen

Druk de fysieke knop in:
- Als alarm actief: alarm stopt direct
- Altijd: HA event `esphome.button_pressed` wordt gestuurd

Controleer via: Ontwikkeltools → Evenementen → luisteren naar `esphome.button_pressed`

### 7.4 OTA Update testen

Maak een kleine wijziging in de ESPHome configuratie en installeer via:
ESPHome add-on → Zigbee Wekker → Installeren → **Installeren via WiFi**

---

## Stap 8: Behuizing Monteren (optioneel)

1. Print `3d-models/case-v1.stl` (body en deksel apart)
2. Volg de assemblage instructies in `3d-models/README.md`
3. Monteer alle componenten in de behuizing
4. Klik het deksel op de body

---

## Problemen?

Zie [TROUBLESHOOTING.md](TROUBLESHOOTING.md) voor oplossingen bij veelvoorkomende problemen.

## Vragen?

Open een [GitHub Issue](https://github.com/natuurwaarnemer/Zigbee-alarm-clock/issues)
met een beschrijving van het probleem en de ESPHome logs.

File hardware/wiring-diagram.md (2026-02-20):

# Aansluitschema - Zigbee Wekker

## Overzicht

Alle verbindingen zijn 3.3V logica. De ESP32-C6 wordt gevoed via USB-C (5V).
De interne 3.3V regelaar op het development board voorziet alle componenten.

## ⚠️ Belangrijk: D-nummers vs GPIO-nummers

De Seeed Studio XIAO ESP32-C6 heeft labels op de pinnen (D0-D10) die NIET overeenkomen met de GPIO nummers!

**Voorbeeld:**
- **D4** op het board = **GPIO22** in de code
- **D5** op het board = **GPIO23** in de code
- **D8** op het board = **GPIO19** in de code
- **D9** op het board = **GPIO20** in de code

In ESPHome configuratie gebruik je altijd de **GPIO nummers**, niet de D-nummers!

## Aansluittabel

| Component | Pin | XIAO ESP32-C6 Pin | GPIO | Notities |
|---|-----|---|---|---|
| OLED Display | VCC | 3.3V | - | Voeding |
| OLED Display | GND | GND | - | Ground |
| OLED Display | SDA | D4 | GPIO22 | I2C Data |
| OLED Display | SCL | D5 | GPIO23 | I2C Clock |
| Buzzer | + | D8 | GPIO19 | PWM output |
| Buzzer | - | GND | - | Ground |
| Button | Pin 1 | D9 | GPIO20 | Met interne pull-up |
| Button | Pin 2 | GND | - | Ground |
| ESP32-C6 | USB-C | 5V adapter | - | Voeding |

## ASCII Aansluitdiagram

```
                    ESP32-C6 (Seeed Studio XIAO C6)
                    ┌─────────────────────────────┐
               3.3V ┤ 3V3                     GND ├─── GND (gemeenschappelijk)
               GND  ┤ GND                     5V  ├─── USB-C ingang
             GPIO22 ┤ D4/GPIO22           GPIO0   ├
             GPIO23 ┤ D5/GPIO23           GPIO1   ├
             GPIO19 ┤ D8/GPIO19           GPIO2   ├
             GPIO20 ┤ D9/GPIO20           GPIO3   ├
                    │                             │
                    └─────────────────────────────┘
                           │     │    │    │
                         USB-C   │    │    │
                         5V IN   │    │    │
                                 │    │    │
                    ┌────────────┘    │    └─────────────────┐
                    │                │                       │
                    ▼                ▼                       ▼
             ┌──────────┐    ┌──────────────┐        ┌──────────┐
             │   OLED   │    │    Buzzer    │        │   Knop   │
             │ SSD1306  │    │  (Actief)    │        │ (Momenteel│
             │ 128x64   │    │              │        │ normaal   │
             │ I2C 0x3C │    │   + aan D8   │        │  open)    │
             │          │    │   (GPIO19)   │        │           │
             │VCC → 3.3V│    │   - aan GND  │        │Pin1→D9    │
             │GND → GND │    └──────────────┘        │  (GPIO20) │
             │SDA→ D4   │                            │Pin2→GND   │
             │  (GPIO22)│                            └──────────┘
             │SCL→ D5   │
             │  (GPIO23)│
             └──────────┘
```

## Gedetailleerde Stap-voor-Stap Aansluiting

### 1. OLED Display (SSD1306 1.3" I2C)

Het OLED display heeft 4 aansluitingen. Let op de volgorde op jouw module
(kan verschillen per fabrikant):

```
Typische pinout 1.3" OLED:
┌─────────────────────────┐
│  GND  VCC  SCL  SDA     │  ← pins aan onderzijde
└─────────────────────────┘
```

| Display Pin | ESP32-C6 | Kleur |
|---|---|---|
| GND | GND | Zwart |
| VCC | **3.3V** (niet 5V!) | Rood |
| SCL | D5 (GPIO23) | Geel |
| SDA | D4 (GPIO22) | Blauw |

⚠️ **Waarschuwing:** Sluit nooit 5V aan op de OLED VCC. Dit beschadigt het
display permanent!

### 2. Buzzer (Actieve Piezo Buzzer)

Een **actieve** buzzer maakt een toon zolang spanning aanwezig is.
Een **passieve** buzzer heeft PWM signaal nodig (ook ondersteund).

```
Buzzer aansluiting:
┌──────────┐
│  BUZZER  │
│   + (lang│───────── D8 (GPIO19)
│   - (kort│───────── GND
└──────────┘
```

| Buzzer Pin | ESP32-C6 |
|---|---|
| + (positief, langere pin) | D8 (GPIO19) |
| - (negatief, kortere pin) | GND |

💡 **Tip:** De meeste buzzer modules hebben een `+` markering. Verbind die
met D8 (GPIO19). Test zonder behuizing voor je alles samenbouwt.

### 3. Drukknop

Een momenteel normaal-open (NO) drukknop met 2 aansluitingen:

```
Knop aansluiting (2-draads):
┌──────────┐
│   KNOP   │
│  Pin 1   │───── D9 (GPIO20, interne pull-up)
│  Pin 2   │───── GND
└──────────┘
```

De interne pull-up weerstand is ingeschakeld in software. De knop trekt GPIO20
naar GND bij indrukken.

### 4. Voeding

Gebruik een betrouwbare USB-C adapter van minimaal 1A (5V).

```
USB-C Adapter
     │
     ▼
ESP32-C6 USB-C poort
     │
     ├─── 3.3V intern geregeld → OLED VCC
     └─── GND gemeenschappelijk → OLED GND, Buzzer -, Knop Pin 2
```

## Componentspecificaties

### ESP32-C6 (Seeed Studio XIAO ESP32C6)
- Spanning: 3.3V logica, 5V voeding via USB-C
- WiFi: 802.11 b/g/n (2.4 GHz)
- Zigbee: IEEE 802.15.4 (ingebouwd)
- GPIO: 3.3V logica, max 12 mA per pin
- Afmetingen: 21 x 17.5 mm

### OLED Display (SSD1306)
- Voedingsspanning: 3.3V (sommige modules 3.3-5V)
- Communicatie: I2C, adres 0x3C (standaard)
- Resolutie: 128x64 pixels
- Afmetingen display: ~35 x 28 mm (module ~38 x 38 mm)
- Stroomverbruik: ~20 mA bij vol wit scherm

### Buzzer (Actieve Piezo)
- Type: Actieve buzzer (ingebouwde oscillator)
- Spanning: 3.3V - 5V
- Stroom: ~30 mA
- Frequentie: 2300 Hz (typisch voor actieve buzzers)
- Of: Passieve piezo - gecontroleerd via PWM

### Drukknop (DE-GQ19H-10)
- Type: Momenteel normaal-open (NO)
- Diameter: 19 mm
- Schakelspanning: max 250V AC / 30V DC
- Stroom: max 3A
- Merk: ook compatibele 12 mm knoppen werken

## Veiligheidsnotities

> ⚠️ **Controleer polariteit** voor je de voeding aansluit!

1. **OLED op 3.3V**: Sluit nooit 5V aan op de OLED VCC-pin.
2. **GPIO max stroom**: Max 12 mA per GPIO-pin. Buzzer ~30 mA kan direct worden
   aangesloten via D8/GPIO19 (LEDC PWM regelt de duty cycle).
3. **ESD bescherming**: Raak de GPIO-pinnen niet aan met statisch geladen vingers.
4. **Test voor behuizing**: Test alle verbindingen voor je alles in de behuizing bouwt.
5. **Voedingspolariteit**: USB-C is polariteitsbestendig.
6. **Kortsluiting voorkomen**: Gebruik behuizing of isolatietape voor onbedekte aansluitingen.

## Verificatie

### I2C Scan (controleer OLED adres)
Gebruik de ESPHome logs of deze seriële commando's om te verifiëren:

```
# In ESPHome: zet scan: true in i2c sectie
# Controleer log output voor: Found i2c device at address 0x3C
```

### LED Test
De ESP32-C6 XIAO heeft een ingebouwde LED op GPIO15. Als de LED knippert
na het flashen, werkt de firmware.

### Button Test  
Druk de knop in. In de ESPHome logs zie je:
```
[D] [binary_sensor:036] 'Wekker Knop': Sending state ON
```

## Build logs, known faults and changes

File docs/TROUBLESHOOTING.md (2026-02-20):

# Veelvoorkomende Problemen - Zigbee Wekker

## Display Problemen

### Display blijft zwart / I2C device niet gevonden

### Symptoom
- ESPHome log toont: "I2C device not found at address 0x3C"
- Display blijft compleet zwart
- Geen foutmeldingen over display driver

### Oorzaak
Waarschijnlijk zijn de I2C pinnen verkeerd aangesloten. De XIAO ESP32-C6 heeft verwarrende pin labels!

### Oplossing
1. Controleer dat je de OLED hebt aangesloten op:
   - SDA → **D4** (staat GPIO22 op het schema, NIET D6!)
   - SCL → **D5** (staat GPIO23 op het schema, NIET D7!)
2. De D-nummers op de pins komen NIET overeen met GPIO nummers
3. Zie hardware/wiring-diagram.md voor de correcte aansluitingen

### Test
In ESPHome logs (na herstarten), moet je zien:
```
[I][i2c.arduino:071]: Results from i2c bus scan:
[I][i2c.arduino:077]: Found i2c device at address 0x3C
```

Als je dit NIET ziet, zijn de I2C pinnen verkeerd aangesloten.

---

### Display blijft zwart / toont niets

**Mogelijke oorzaken en oplossingen:**

1. **Verkeerde voedingsspanning**
   - Controleer of VCC verbonden is met **3.3V**, niet 5V
   - Meet met een multimeter: 3.3V tussen VCC en GND op het display

2. **Verkeerd I2C adres**
   - Standaard adres is `0x3C`, maar sommige modules gebruiken `0x3D`
   - Zet `scan: true` in de i2c sectie van de ESPHome configuratie
   - Herstart en controleer de logs: je ziet `Found i2c device at address 0x3C`
   - Als je `0x3D` ziet: verander het adres in de yaml

3. **SDA/SCL verwisseld**
   - D4 (GPIO22) = SDA, D5 (GPIO23) = SCL
   - Controleer de kabels nog eens

4. **Slechte verbinding**
   - Controleer of alle jumper wires stevig zijn
   - Test met een I2C scanner sketch in Arduino IDE

5. **Defect display of module**
   - Test met een andere I2C scanner op een andere microcontroller

---

### Display toont ruis / rare tekens

- **Slechte I2C verbinding:** Gebruik kortere kabels (max 30 cm)
- **Interferentie:** Houd display kabels uit de buurt van de buzzer bedrading
- **Verkeerd display model:** Controleer of het `SSD1306 128x64` is, niet SH1106
  - Als je een SH1106 display hebt: verander `model: "SSD1306 128x64"` naar `model: "SH1106 128x64"` in de yaml

---

## Alarm Problemen

### Alarm gaat niet af op de ingestelde tijd

1. **Tijdsynchronisatie controleren**
   - Ga naar Ontwikkeltools → Sjablonen in Home Assistant
   - Typ: `{{ now() }}` - dit toont de HA systeemtijd
   - Controleer of de wekker dezelfde tijd toont als HA

2. **Dag schakelaar controleren**
   - Is de schakelaar voor die dag AAN?
   - Is de **hoofdschakelaar** AAN?

3. **Tijdzone controleren**
   - De configuratie gebruikt `Europe/Amsterdam`
   - Als je in een andere tijdzone bent: pas aan in de yaml

4. **ESPHome logs controleren**
   - Open ESPHome → Logs van het apparaat
   - Zoek naar `[I] [script:] check_alarms`
   - Je ziet elke minuut een check

5. **Alarm minuten controleren**
   - Alarm controle gebeurt op seconde 0 van elke minuut
   - Er kan 1 minuut vertraging zijn

---

### Buzzer maakt geen geluid

1. **D8 (GPIO19) controleren**
   - Verbinding buzzer + naar D8 (GPIO19), - naar GND

2. **Actieve vs passieve buzzer**
   - Actieve buzzer: reageert op vaste spanning (werkt direct)
   - Passieve buzzer: heeft PWM nodig (ook ondersteund)
   - Test: sluit de buzzer direct aan op 3.3V en GND - als hij piept, is het een actieve buzzer

3. **PWM frequentie**
   - De firmware gebruikt 1000 Hz PWM
   - Sommige passieve buzzers reageren beter op andere frequenties
   - Pas `frequency: 1000 Hz` aan in de yaml

4. **Buzzer defect**
   - Test met een multimeter: meet de weerstand van de buzzer (typisch 8-32 Ohm)

---

### Alarm stopt niet na knop indrukken

1. **Knop verbinding controleren**
   - D9 (GPIO20) naar knop Pin 1, GND naar knop Pin 2
   - Meet met multimeter: kortsluiting wanneer knop ingedrukt?

2. **Pull-up controleren**
   - GPIO20 moet `HIGH` zijn in rust en `LOW` bij indrukken
   - Controleer met: Ontwikkeltools → Staten → zoek `binary_sensor.zigbee_wekker_wekker_knop`

3. **Debounce problemen**
   - De debounce is 20ms. Bij bouncy knoppen: verhoog naar 50ms
   - Zoek in yaml: `delayed_on: 20ms` en vergroot de waarde

---

## WiFi / Verbindingsproblemen

### Wekker verbindt niet met WiFi

1. **Credentials controleren**
   - Controleer `wifi_ssid` en `wifi_password` in `secrets.yaml`
   - WiFi naam is hoofdlettergevoelig: `MijnWifi` ≠ `mijnwifi`

2. **2.4 GHz WiFi**
   - ESP32-C6 ondersteunt **alleen 2.4 GHz** WiFi
   - Zorg dat je 2.4 GHz netwerk actief is (niet alleen 5 GHz)

3. **Fallback hotspot**
   - Als WiFi mislukt: de wekker maakt een eigen hotspot "Wekker Fallback"
   - Verbind hiermee en configureer WiFi via het captive portal

4. **WiFi signaal te zwak**
   - Controleer `sensor.zigbee_wekker_wifi_signaalsterkte` in HA
   - Onder -80 dBm: problemen verwacht
   - Gebruik een WiFi extender of verplaats de router dichter bij

5. **ESP32-C6 herstarten**
   - Haal de USB stekker er uit en steek hem er weer in
   - Of via HA: Ontwikkeltools → Services → `button.zigbee_wekker_restart`

---

### Home Assistant ziet het apparaat niet

1. **Zelfde netwerk**
   - HA en wekker moeten op **hetzelfde** WiFi netwerk zitten

2. **mDNS / Discovery**
   - HA gebruikt mDNS (`.local` adressen) voor ESPHome discovery
   - Sommige routers blokkeren mDNS - probeer het IP-adres direct in te voeren
   - Vind het IP via je router DHCP tabel of scan met een app als "Fing"

3. **API sleutel**
   - Zorg dat de `api_encryption_key` in secrets.yaml overeenkomt
   - Als je opnieuw flasht, gebruik dezelfde sleutel

4. **Firewall**
   - Port 6053 moet open zijn tussen HA en de wekker

---

## ESPHome Compileerfouten

### "Font not found" fout

De configuratie gebruikt Google Fonts. Dit vereist internetverbinding bij compileren.
Als je geen internet hebt:

1. Download het font handmatig
2. Sla op als `esphome/fonts/Roboto-Regular.ttf`
3. Verander in yaml:
   ```yaml
   font:
     - file: "fonts/Roboto-Regular.ttf"
   ```

### "Unknown platform" fout

- Controleer of je de laatste versie van ESPHome hebt
- Update via: Instellingen → Add-ons → ESPHome → Update

### Compileren duurt erg lang of mislukt

- Eerste compilatie kan 10-15 minuten duren (ESP-IDF framework)
- Zorg voor voldoende vrije schijfruimte (>500 MB) op je HA systeem
- Herstart de ESPHome add-on en probeer opnieuw

---

## Display Helderheid

### Display te helder 's nachts

De automatische dimmer is actief tussen 22:00 en 07:00.
Pas de uren aan in de yaml als gewenst:

```yaml
// Zoek in de display lambda:
bool night_mode = (now.hour >= 22 || now.hour < 7);
// Verander 22 en 7 naar gewenste uren
```

---

## Overige Problemen

### Wekker toont verkeerde tijd

1. Verbinding met HA verbroken - wekker synchroniseert elke keer opnieuw bij verbinding
2. Verkeerde tijdzone - controleer `timezone: "Europe/Amsterdam"` in de yaml
3. NTP synchronisatie: de sntp fallback time server is geconfigureerd, maar vereist internet

### OTA Update mislukt

1. Zorg dat wekker en HA op hetzelfde netwerk zitten
2. Probeer via USB als WiFi OTA niet werkt
3. Controleer het OTA wachtwoord in secrets.yaml

---

## Nog steeds problemen?

1. Bekijk de ESPHome **logs** voor foutmeldingen:
   ESPHome add-on → klik op apparaat → Logs

2. Open een **GitHub Issue** met:
   - Beschrijving van het probleem
   - Inhoud van de ESPHome logs (geen secrets!)
   - Foto van de bedrading

3. Bezoek het **ESPHome forum**: [community.home-assistant.io](https://community.home-assistant.io/c/esphome/)

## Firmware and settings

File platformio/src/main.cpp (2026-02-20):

// main.cpp - Zigbee Alarm Clock - Main entry point
// Hardware: ESP32-C6 (Seeed Studio)
//   - OLED SSD1306 1.3" I2C:  SDA=GPIO6, SCL=GPIO7
//   - Piezo Buzzer (active):  GPIO8
//   - Button (momentary NO):  GPIO9 (internal pull-up, active LOW)
//   - Power: USB-C 5V

#include <Arduino.h>
#include <time.h>
#include "display.h"
#include "alarm.h"
#include "zigbee.h"

// ---- Configuration ----
#define BUTTON_DEBOUNCE_MS 50

// ---- State ----
static bool     s_button_last_state = HIGH;
static uint32_t s_button_changed_ms = 0;
static uint32_t s_last_alarm_check_ms = 0;
static uint32_t s_last_display_update_ms = 0;
static bool     s_master_alarm_enabled = true;

// ---- Prototypes ----
static void handle_button(void);
static void sync_time_from_zigbee(void);
static void on_alarm_config_received(uint8_t day, uint8_t hour,
                                     uint8_t minute, bool enabled);

// ============================================================
// Arduino setup
// ============================================================
void setup() {
    Serial.begin(115200);
    Serial.println("[Boot] Zigbee Alarm Clock starting...");

    // Initialize display first (shows splash screen)
    if (!display_init()) {
        Serial.println("[Display] WARNING: SSD1306 not found at 0x3C");
    }

    // Initialize alarm module (loads NVS config, sets up PWM, configures button)
    alarm_init();

    // Register Zigbee alarm config callback
    zigbee_set_alarm_config_callback(on_alarm_config_received);

    // Initialize and start Zigbee
    zigbee_init();
    if (!zigbee_start()) {
        Serial.println("[Zigbee] Failed to start - check Zigbee coordinator");
    }

    Serial.println("[Boot] Setup complete");
}

// ============================================================
// Arduino main loop
// ============================================================
void loop() {
    uint32_t now_ms = millis();

    // Process Zigbee stack events (must be called every loop iteration)
    zigbee_update();

    // Handle button press with debouncing
    handle_button();

    // Update alarm buzzer state machine
    alarm_update();

    // Check alarms every minute (at second 0, approximately)
    if (now_ms - s_last_alarm_check_ms >= 60000UL) {
        s_last_alarm_check_ms = now_ms;

        if (s_master_alarm_enabled) {
            // Get current time from system clock (set via Zigbee time cluster)
            time_t t = time(nullptr);
            struct tm* tm_info = localtime(&t);
            if (tm_info && t > 1000000) { // Sanity check - time must be set
                // Convert tm_wday (0=Sunday) to 1=Monday..7=Sunday
                uint8_t dow = (tm_info->tm_wday == 0) ? 7 : tm_info->tm_wday;
                alarm_check(tm_info->tm_hour, tm_info->tm_min, dow);
            }
        }
    }

    // Update display at 2 Hz (500ms interval)
    if (now_ms - s_last_display_update_ms >= 500UL) {
        s_last_display_update_ms = now_ms;

        if (alarm_is_active()) {
            display_update_alarm();
        } else {
            time_t t = time(nullptr);
            struct tm* tm_info = localtime(&t);
            bool time_valid = (t > 1000000);

            uint8_t hour = time_valid ? tm_info->tm_hour : 0;
            uint8_t min  = time_valid ? tm_info->tm_min  : 0;
            uint8_t sec  = time_valid ? tm_info->tm_sec  : 0;
            uint8_t mday = time_valid ? tm_info->tm_mday : 1;
            uint8_t mon  = time_valid ? (tm_info->tm_mon + 1) : 1;
            uint8_t dow  = time_valid ?
                ((tm_info->tm_wday == 0) ? 7 : tm_info->tm_wday) : 1;

            char next_alarm_buf[6];
            alarm_get_next_str(next_alarm_buf, hour, min, dow);

            display_set_brightness_auto(hour);
            display_update_clock(
                hour, min, sec, mday, mon, dow,
                next_alarm_buf,
                zigbee_is_connected(),
                s_master_alarm_enabled);
        }
    }
}

// ============================================================
// Button handling
// ============================================================
static void handle_button(void) {
    bool current = digitalRead(BUTTON_PIN);
    uint32_t now_ms = millis();

    if (current != s_button_last_state) {
        s_button_changed_ms = now_ms;
        s_button_last_state = current;
    }

    // Debounce: wait BUTTON_DEBOUNCE_MS ms after last change
    if ((now_ms - s_button_changed_ms) >= BUTTON_DEBOUNCE_MS && current == LOW) {
        // Button pressed (active LOW)
        if (alarm_is_active()) {
            alarm_stop();
            zigbee_send_alarm_status(false);
            Serial.println("[Button] Alarm stopped by button press");
        }
        // Always send button press event to coordinator
        zigbee_send_button_press();
        Serial.println("[Button] Button press sent to coordinator");

        // Wait for button release before next action
        while (digitalRead(BUTTON_PIN) == LOW) {
            zigbee_update();
            delay(10);
        }
    }
}

// ============================================================
// Callback: alarm configuration received via Zigbee
// ============================================================
static void on_alarm_config_received(uint8_t day, uint8_t hour,
                                     uint8_t minute, bool enabled) {
    Serial.printf("[Zigbee] Alarm config: day=%d %02d:%02d enabled=%d\n",
                  day, hour, minute, enabled);
    alarm_set_config(day, hour, minute, enabled);
}

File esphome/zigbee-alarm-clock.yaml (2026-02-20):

# ============================================================
# Zigbee Alarm Clock - ESPHome Configuration
# Hardware: ESP32-C6 (Seeed Studio) + SSD1306 OLED + Piezo Buzzer + Button
# Primary connectivity: WiFi (Zigbee upgrade path in platformio/)
# ============================================================

# ------- Basic device info -------
esphome:
  name: zigbee-alarm-clock
  friendly_name: "Zigbee Wekker"
  on_boot:
    priority: 600
    then:
      - script.execute: display_startup
      - lambda: |-
          id(alarm_active) = false;
          id(next_alarm_str) = std::string("--:--");

esp32:
  board: esp32-c6-devkitc-1
  framework:
    type: esp-idf
    version: recommended

# ------- Logger -------
logger:
  level: INFO
  logs:
    ssd1306_base: WARNING
    i2c: WARNING

# ------- WiFi -------
wifi:
  ssid: !secret wifi_ssid
  password: !secret wifi_password
  # Static IP (optional, improves boot time)
  # manual_ip:
  #   static_ip: 192.168.1.100
  #   gateway: 192.168.1.1
  #   subnet: 255.255.255.0
  ap:
    # Fallback hotspot when WiFi is unavailable
    ssid: "Wekker Fallback"
    password: "wekker123"

captive_portal:

# ------- Home Assistant API -------
api:
  encryption:
    key: !secret api_encryption_key
  services:
    # Service to trigger alarm from HA (for testing)
    - service: trigger_alarm
      then:
        - script.execute: alarm_start
    # Service to stop alarm from HA
    - service: stop_alarm
      then:
        - script.execute: alarm_stop

# ------- OTA Updates -------
ota:
  - platform: esphome
    password: !secret ota_password

# ------- I2C Bus (OLED display) -------
i2c:
  sda: GPIO22  # D4 on XIAO ESP32-C6
  scl: GPIO23  # D5 on XIAO ESP32-C6
  scan: true
  id: bus_a

# ------- Fonts -------
font:
  # Large font for time display (HH:MM)
  - file: "gfonts://Roboto"
    id: font_time
    size: 42
    glyphs: "0123456789:"

  # Medium font for date and alarm
  - file: "gfonts://Roboto"
    id: font_medium
    size: 16
    glyphs: "0123456789abcdefghijklmnopqrstuvwxyzABCDEFGHIJKLMNOPQRSTUVWXYZ :.-"

  # Small font for status icons/labels
  - file: "gfonts://Roboto"
    id: font_small
    size: 12
    glyphs: "0123456789abcdefghijklmnopqrstuvwxyzABCDEFGHIJKLMNOPQRSTUVWXYZ :.-!?"

# ------- OLED Display (SSD1306, 1.3", 128x64, address 0x3C) -------
display:
  - platform: ssd1306_i2c
    model: "SSD1306 128x64"
    address: 0x3C
    id: oled
    update_interval: 1s
    lambda: |-
      // Determine display brightness based on time (dim at night 22:00-07:00)
      auto now = id(homeassistant_time).now();
      bool night_mode = (now.hour >= 22 || now.hour < 7);
      it.set_contrast(night_mode ? 10 : 255);

      if (id(alarm_active)) {
        // --- ALARM ACTIVE: blink display ---
        static bool blink_state = false;
        blink_state = !blink_state;
        if (blink_state) {
          it.fill(COLOR_ON);
          it.print(64, 20, id(font_time), COLOR_OFF, TextAlign::CENTER, "ALARM");
          it.print(64, 50, id(font_medium), COLOR_OFF, TextAlign::CENTER, "Druk op knop!");
        } else {
          it.clear();
          it.print(64, 20, id(font_time), COLOR_ON, TextAlign::CENTER, "ALARM");
          it.print(64, 50, id(font_medium), COLOR_ON, TextAlign::CENTER, "Druk op knop!");
        }
        return;
      }

      it.clear();

      // --- Time (large, centered) ---
      if (now.is_valid()) {
        char time_str[6];
        snprintf(time_str, sizeof(time_str), "%02d:%02d", now.hour, now.minute);
        it.print(64, 0, id(font_time), TextAlign::TOP_CENTER, time_str);
      } else {
        it.print(64, 0, id(font_time), TextAlign::TOP_CENTER, "--:--");
      }

      // --- Date and day of week ---
      if (now.is_valid()) {
        const char* days[] = {"Zo", "Ma", "Di", "Wo", "Do", "Vr", "Za"};
        char date_str[20];
        snprintf(date_str, sizeof(date_str), "%s %02d-%02d",
                 days[now.day_of_week - 1], now.day_of_month, now.month);
        it.print(0, 46, id(font_small), date_str);
      }

      // --- Next alarm ---
      it.printf(0, 57, id(font_small), "A:%s", id(next_alarm_str).c_str());

      // --- WiFi status icon (top right) ---
      if (id(wifi_connected).state) {
        it.print(128, 0, id(font_small), TextAlign::TOP_RIGHT, "W");
      } else {
        it.print(128, 0, id(font_small), TextAlign::TOP_RIGHT, "!");
      }

      // --- Master alarm icon (top right, below wifi) ---
      if (id(alarm_master).state) {
        it.print(128, 12, id(font_small), TextAlign::TOP_RIGHT, "ON");
      } else {
        it.print(128, 12, id(font_small), TextAlign::TOP_RIGHT, "off");
      }
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

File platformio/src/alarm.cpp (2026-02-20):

// alarm.cpp - Alarm management implementation
// Hardware: ESP32-C6 + Piezo buzzer on GPIO8 + Button on GPIO9

#include "alarm.h"
#include <Arduino.h>
#include <nvs_flash.h>
#include <nvs.h>
#include <driver/ledc.h>
#include <string.h>
#include <stdio.h>

// ---- Internal state ----
static alarm_config_t s_alarms[ALARM_COUNT];
static alarm_state_t  s_state = {false, 0, 0};

// Buzzer timing state (managed in alarm_update)
static uint32_t s_buzzer_next_event_ms = 0;
static bool     s_buzzer_on            = false;
static uint8_t  s_beep_phase           = 0; // 0..3 for beep-pause pattern

// LEDC channel for buzzer PWM
#define LEDC_CHANNEL LEDC_CHANNEL_0
#define LEDC_TIMER   LEDC_TIMER_0
#define LEDC_FREQ_HZ 1000
#define LEDC_RES     LEDC_TIMER_10_BIT  // 0-1023

// ---- Internal helpers ----

static void buzzer_set_volume(uint8_t volume_pct) {
    // Convert 0-100% to 0-1023 duty (10-bit resolution)
    uint32_t duty = (volume_pct * 1023) / 100;
    ledc_set_duty(LEDC_HIGH_SPEED_MODE, LEDC_CHANNEL, duty);
    ledc_update_duty(LEDC_HIGH_SPEED_MODE, LEDC_CHANNEL);
}

static void buzzer_off(void) {
    ledc_set_duty(LEDC_HIGH_SPEED_MODE, LEDC_CHANNEL, 0);
    ledc_update_duty(LEDC_HIGH_SPEED_MODE, LEDC_CHANNEL);
}

// ---- Public API ----

void alarm_init(void) {
    // Initialize NVS
    esp_err_t ret = nvs_flash_init();
    if (ret == ESP_ERR_NVS_NO_FREE_PAGES || ret == ESP_ERR_NVS_NEW_VERSION_FOUND) {
        nvs_flash_erase();
        nvs_flash_init();
    }

    // Configure button GPIO with internal pull-up
    pinMode(BUTTON_PIN, INPUT_PULLUP);

    // Configure buzzer PWM via LEDC
    ledc_timer_config_t timer_cfg = {
        .speed_mode      = LEDC_HIGH_SPEED_MODE,
        .duty_resolution = LEDC_RES,
        .timer_num       = LEDC_TIMER,
        .freq_hz         = LEDC_FREQ_HZ,
        .clk_cfg         = LEDC_AUTO_CLK,
    };
    ledc_timer_config(&timer_cfg);

    ledc_channel_config_t ch_cfg = {
        .gpio_num   = BUZZER_PIN,
        .speed_mode = LEDC_HIGH_SPEED_MODE,
        .channel    = LEDC_CHANNEL,
        .intr_type  = LEDC_INTR_DISABLE,
        .timer_sel  = LEDC_TIMER,
        .duty       = 0,
        .hpoint     = 0,
    };
    ledc_channel_config(&ch_cfg);

    // Load saved alarm configs
    alarm_load_from_nvs();
}

void alarm_check(uint8_t hour, uint8_t minute, uint8_t dow) {
    if (s_state.active) return; // Already sounding

    // dow is 1=Monday..7=Sunday, maps to index 0..6
    uint8_t idx = (dow - 1) % ALARM_COUNT;
    if (s_alarms[idx].enabled &&
        s_alarms[idx].hour   == hour &&
        s_alarms[idx].minute == minute) {
        alarm_start();
    }
}

void alarm_start(void) {
    s_state.active           = true;
    s_state.current_volume   = 0;
    s_state.triggered_at_ms  = millis();
    s_beep_phase             = 0;
    s_buzzer_on              = false;
    s_buzzer_next_event_ms   = millis(); // Start immediately
}

void alarm_stop(void) {
    s_state.active         = false;
    s_state.current_volume = 0;
    s_buzzer_on            = false;
    buzzer_off();
}

void alarm_update(void) {
    if (!s_state.active) return;

    uint32_t now_ms = millis();
    if (now_ms < s_buzzer_next_event_ms) return;

    // Pattern: beep-beep pause (300ms on, 200ms off, 300ms on, 1200ms pause)
    switch (s_beep_phase) {
        case 0: // First beep ON
            if (s_state.current_volume < BUZZER_MAX_VOLUME) {
                s_state.current_volume = (uint8_t)
                    MIN(s_state.current_volume + BUZZER_FADE_STEP, BUZZER_MAX_VOLUME);
            }
            buzzer_set_volume(s_state.current_volume);
            s_buzzer_next_event_ms = now_ms + 300;
            s_beep_phase = 1;
            break;
        case 1: // First beep OFF
            buzzer_off();
            s_buzzer_next_event_ms = now_ms + 200;
            s_beep_phase = 2;
            break;
        case 2: // Second beep ON
            buzzer_set_volume(s_state.current_volume);
            s_buzzer_next_event_ms = now_ms + 300;
            s_beep_phase = 3;
            break;
        case 3: // Pause
            buzzer_off();
            s_buzzer_next_event_ms = now_ms + 1200;
            s_beep_phase = 0;
            break;
    }
}

const alarm_config_t* alarm_get_config(uint8_t dow) {
    uint8_t idx = (dow - 1) % ALARM_COUNT;
    return &s_alarms[idx];
}

void alarm_set_config(uint8_t dow, uint8_t hour, uint8_t minute, bool enabled) {
    uint8_t idx = (dow - 1) % ALARM_COUNT;
    s_alarms[idx].hour    = hour;
    s_alarms[idx].minute  = minute;
    s_alarms[idx].enabled = enabled;
    alarm_save_to_nvs();
}

bool alarm_is_active(void) {
    return s_state.active;
}

void alarm_get_next_str(char* buf, uint8_t hour, uint8_t minute, uint8_t dow) {
    int current_minutes = hour * 60 + minute;
    int best_ahead      = 10081; // > 7 days in minutes
    int best_h = -1, best_m = -1;

    for (int i = 0; i < ALARM_COUNT; i++) {
        if (!s_alarms[i].enabled) continue;

        int alarm_dow  = i + 1; // 1=Monday..7=Sunday
        int alarm_mins = s_alarms[i].hour * 60 + s_alarms[i].minute;
        int days_ahead = (alarm_dow - dow + 7) % 7;
        int mins_ahead = days_ahead * 1440 + alarm_mins - current_minutes;
        if (mins_ahead <= 0) mins_ahead += 7 * 1440;

        if (mins_ahead < best_ahead) {
            best_ahead = mins_ahead;
            best_h = s_alarms[i].hour;
            best_m = s_alarms[i].minute;
        }
    }

    if (best_h >= 0) {
        snprintf(buf, 6, "%02d:%02d", best_h, best_m);
    } else {
        snprintf(buf, 6, "--:--");
    }
}

void alarm_load_from_nvs(void) {
    nvs_handle_t handle;
    if (nvs_open(NVS_NAMESPACE, NVS_READONLY, &handle) != ESP_OK) {
        // No saved data - use defaults (all disabled, 07:00)
        for (int i = 0; i < ALARM_COUNT; i++) {
            s_alarms[i].hour    = 7;
            s_alarms[i].minute  = 0;
            s_alarms[i].enabled = false;
        }
        return;
    }

    for (int i = 0; i < ALARM_COUNT; i++) {
        char key[16];

        snprintf(key, sizeof(key), "alarm_%d_h", i);
        uint8_t h = 7;
        nvs_get_u8(handle, key, &h);
        s_alarms[i].hour = h;

        snprintf(key, sizeof(key), "alarm_%d_m", i);
        uint8_t m = 0;
        nvs_get_u8(handle, key, &m);
        s_alarms[i].minute = m;

        snprintf(key, sizeof(key), "alarm_%d_en", i);
        uint8_t en = 0;
        nvs_get_u8(handle, key, &en);
        s_alarms[i].enabled = (en != 0);
    }

    nvs_close(handle);
}
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

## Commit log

2026-02-20 Add complete alarm clock project: ESPHome, PlatformIO, HA config, hardware docs, 3D models
    [case-v1.scad]
2026-02-20 Fix duplicate button init and improve dashboard entity label per code review
    [main.cpp]
2026-02-20 Fix GPIO pin mappings for Seeed Studio XIAO ESP32-C6
    [zigbee-alarm-clock.yaml]
2026-02-21 Electrical diagram
    Diagram for easy soldering
